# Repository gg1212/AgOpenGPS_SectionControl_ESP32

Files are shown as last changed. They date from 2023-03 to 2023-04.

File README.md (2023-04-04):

# AgOpenGPS Section Control ESP32 WiFi
This code runs AOG section control on ESP32. 
The ESP32 is connected to my mobile hotspot using WiFi, my laptop running AOG is also connected to the same WiFi hotspot. The AgIO UDP scanner will find the module once you configure the network address in AgIO. Note that you cannot fix the subnet of an Android hotspot so you may have to reconfigure subnet in AgIO if it switched on the phone.

You need to edit the code and add your WiFi SSID and password before uploading the code to ESP32.

That's a wiring diagram for 7sections, main(work) switch and manual/auto switch:

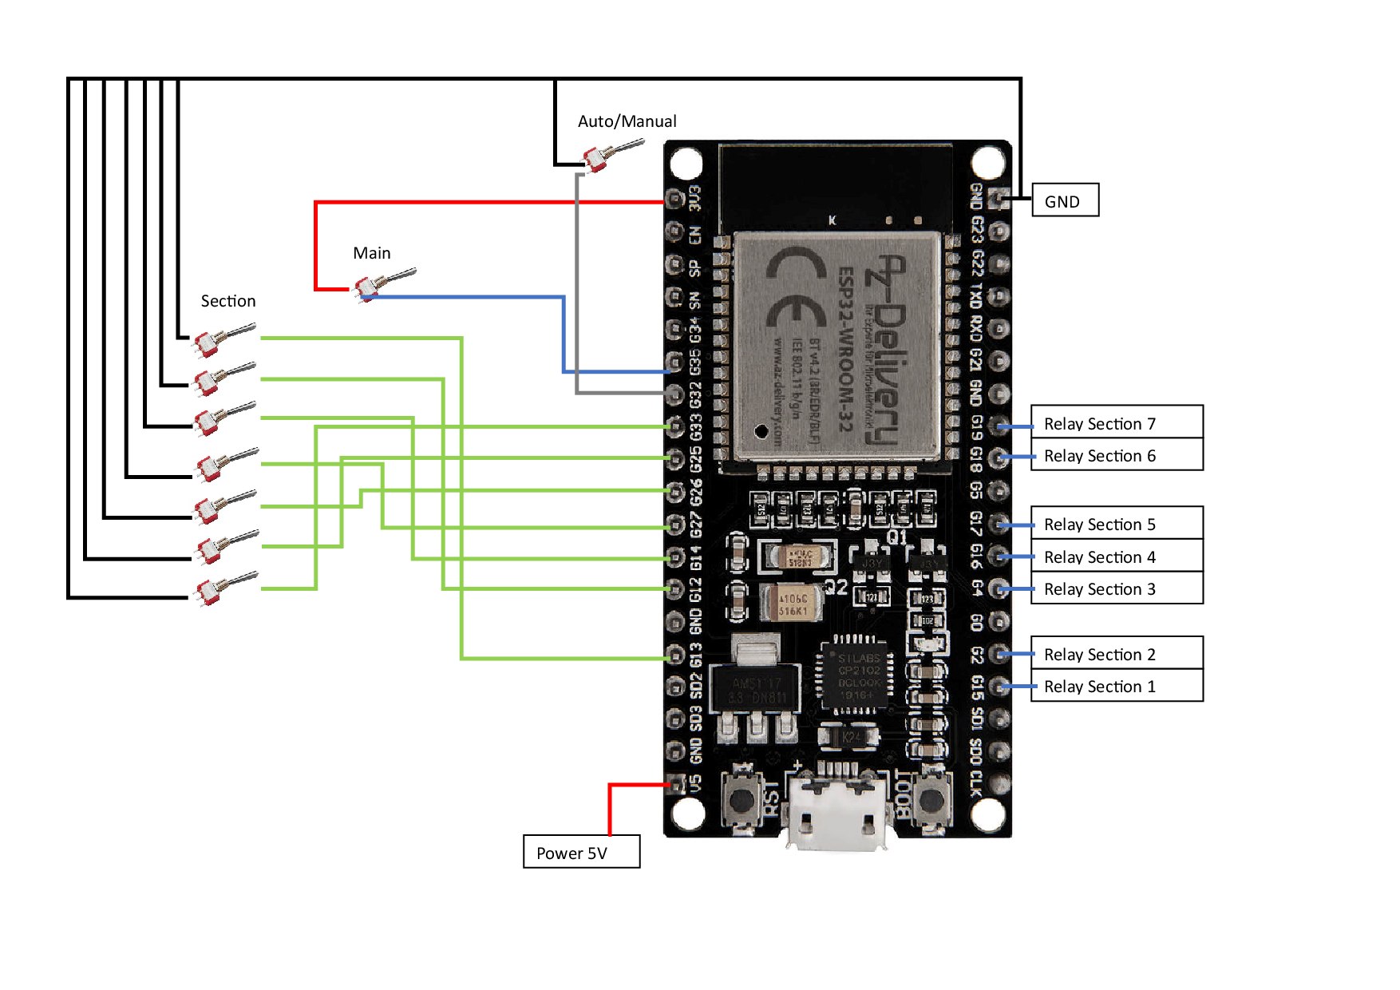
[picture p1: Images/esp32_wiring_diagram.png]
wiring diagram


This code is based on [mtz8302/AOG_SectionControl_ESP32](https://github.com/mtz8302/AOG_SectionControl_ESP32) for which all the rate control and web interface related stuff have been removed. The communication code has also been updated to make it ready for AOG v5.7.2 UDP.

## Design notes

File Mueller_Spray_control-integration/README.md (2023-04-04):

# Mueller Spray Control computer ESP32 Section Control
## Overview
The section control unit is connected between the existing Mueller Spray Control boxes and the sprayer. This allows me to do section control without any modification to the existing boxes and cables.

In manual mode, AOG displays the working area based on the section status.

In automatic mode, AOG controls the relays and the sprayer does GPS automatic section control based on AOG data.

The overview of my setup:

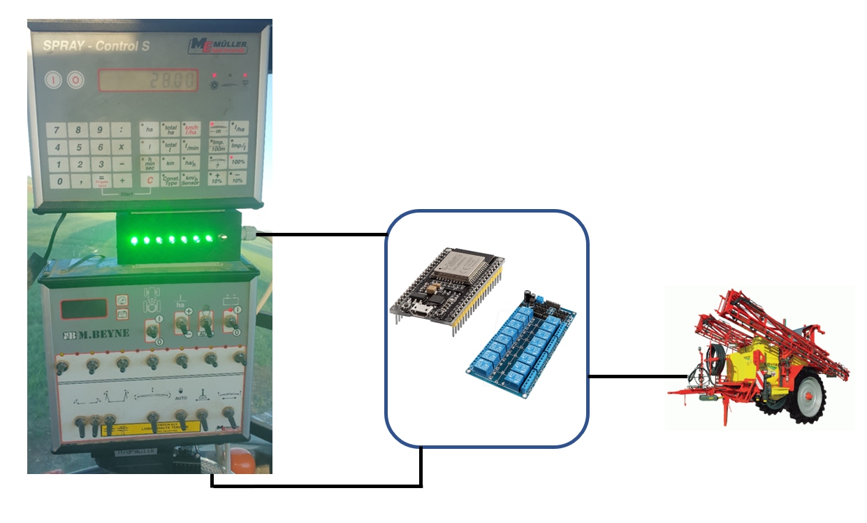
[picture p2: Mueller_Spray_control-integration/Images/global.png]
overview


## Reading section state from reverse polarity valves
My sprayer valves are reverse polarity, so to read the state on the ESP32, a PC817 8 channel board has been used. The section wire on which there is 12v when the section is open has been connected to the PC817 board.
There is also a bypass valve (reverse polarity too) on my sprayer and it has been connected to the 8th channel on the PC817 to activate the main(work) switch.

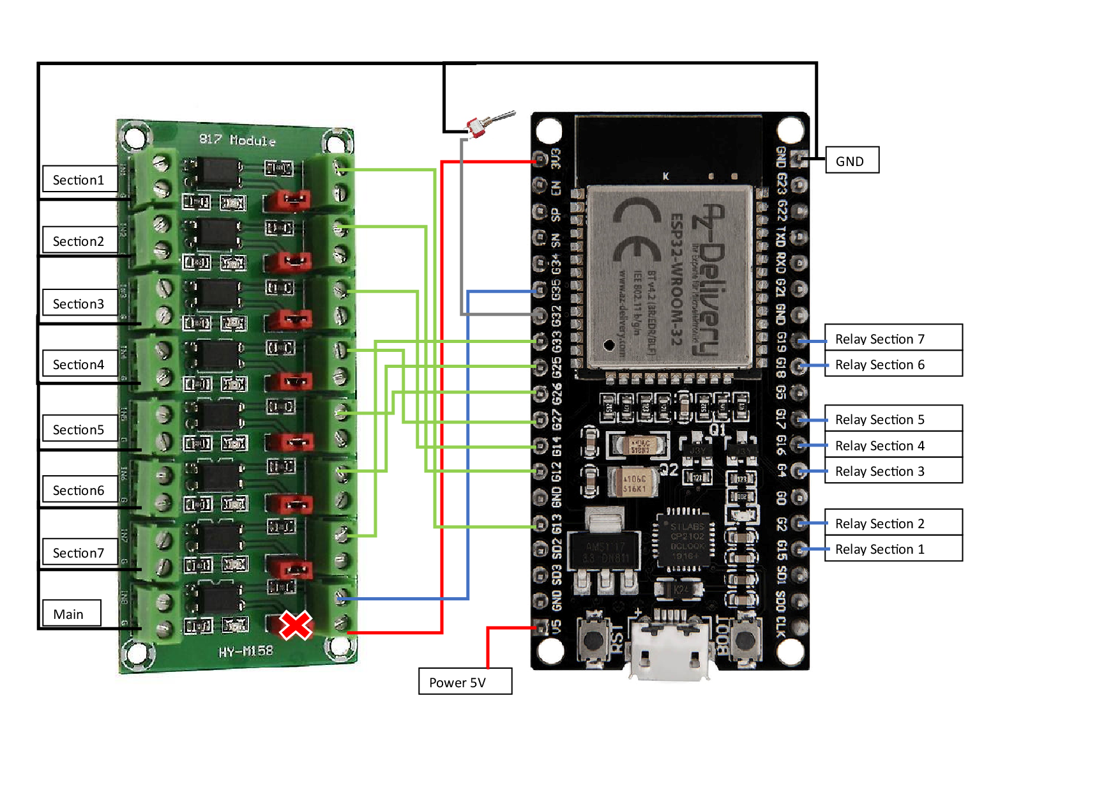
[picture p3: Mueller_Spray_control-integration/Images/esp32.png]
esp32


## Relay board & sending section status to rate computer
### Relay board
Valves are reverse polarity so you need 2 relays per section valve. 12V goes to NC of relay 1 and NO of relay 2. GND goes to NO of relay 1 and NC of relay 2. The section valve is connected to relay 1 & 2 COM.

So for my 7 sections sprayer, 14 relays of a 16 relays board have been used. They have been wired as in the example below.

### Rate controller section state
It is really important that the Spray Control computer knows how many sections are spraying in order to adjust rate correctly. So, the info should be coming from the output of the relays instead of the output of the switches as before. 

A second PC817 optocoupler board has been used to get the 12v status from relay board and switch rate computer pin to GND. Note that it requires to remove the 3K resistor so a wire has been soldered on the board to bypass it.

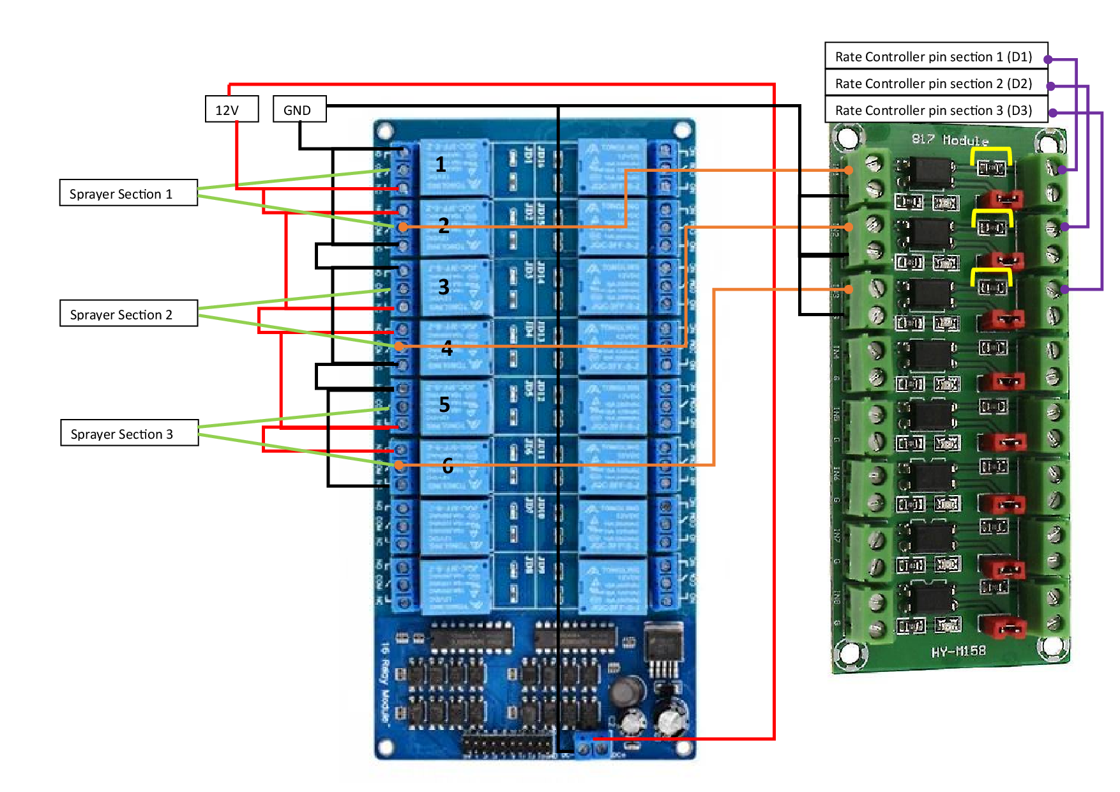
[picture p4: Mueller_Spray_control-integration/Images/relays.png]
relays


## Hardware
A 3D printed box that fits between Mueller Spray Control box and the switches box has been designed, it allows to connect to the Spray Control S box and send the section signal from real status(relay board+optocoupler). In order to centralize the switches, the man/auto switch has been put on this 3D printed box which fits perfectly like a 3rd Mueller box. 7 leds have also added to show the section state based on the relays as the original led only shows the switches state.

The box model is available in [3D](/Mueller_Spray_control-integration/3D) folder.

The connectors between Mueller boxes are Harting 48pins DIN 41612 connectors.

The connectors between Mueller box and sprayer are 30pins DIN 41622 connectors that I ordered at Beyne factory webshop : [30p male](https://erp.beyne.be/fr_BE/shop/product/cnc-30-m-prise-30-poles-m-4485) and [30p female](https://erp.beyne.be/fr_BE/shop/product/cnc-30-v-prise-30-poles-f-4483).

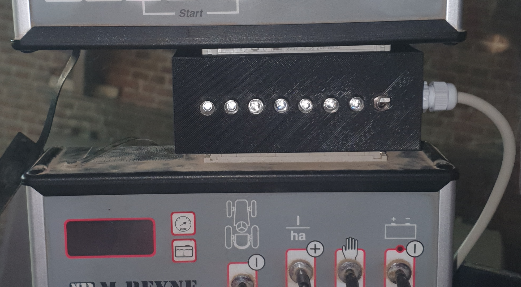
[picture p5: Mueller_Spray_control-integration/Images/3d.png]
3d box


## Mueller Pinout
### Spray Control S 48pins connector

|Pin|To |Info|
|---|---|----|
|Z3|Z3|12v|
|Z4|Z4|GND|
|Z6|Z6|GND|
|Z12|Z12|GND|
|B1|B1||
|B4|B4||
|B5|B5||
|B12|B12||
|B13|B13||
|D1|PC817-1|Section1|
|D2|PC817-2|Section2|
|D3|PC817-3|Section3|
|D4|PC817-4|Section4|
|D5|PC817-5|Section5|
|D6|PC817-6|Section6|
|D7|PC817-7|Section7|
|D13|D13||
|D14|D14||
|D15|D15||
|D16|D16||

### 30pin Sprayer connector
30pin DIN41622 - Input (from box)
|Pin|Info|To|
|--|--|--|
|A1|Rate|A1 Out|
|A2|Rate|A2 Out|
|A3|Main On/Off|PC817-8 + A3 Out|
|A4|Main On/Off|A4 Out|
|A5|Sec1|PC817-1|
|A6|Sec1||
|A7|Sec2|PC817-2|
|A8|Sec2||
|A9|Sec3|PC817-3|
|A10|Sec3||
|B1|Sec4|PC817-4|
|B2|Sec4||
|B3|Sec5|PC817-5|
|B4|Sec5||
|B5|Sec6|PC817-6|
|B6|Sec6||
|B7|Sec7|PC817-7|
|B8|Sec7||
|B9|Sec8|B9 Out|
|B10|Sec8|B10 Out|
|C1|Sec9|C1 Out|
|C2|Sec9|C2 Out|
|C3|12v|C3 + 12V|
|C4|unknow|C4 Out|
|C5|Gnd|C5 + GND|
|C6|unknow|C6 Out|
|C7|unknow|C7 Out|
|C8|unknow|C8 Out|
|C9|unknow|C9 Out|
|C10|unknow|C10 Out|

30pin DIN41622 - Output (To Sprayer)
|Pin|To|
|--|--|
|A1|A1 In|
|A2|A2 In|
|A3|A3 In|
|A4|A4 In|
|A5|Relay|
|A6|Relay|
|A7|Relay|
|A8|Relay|
|A9|Relay|
|A10|Relay|
|B1|Relay|
|B2|Relay|
|B3|Relay|
|B4|Relay|
|B5|Relay|
|B6|Relay|
|B7|Relay|
|B8|Relay|
|B9|B9 In|
|B10|B10 In|
|C1|C1 In|
|C2|C2 In|
|C3|C3 + 12V|
|C4|C4 In|
|C5|C5 + GND|
|C6|C6 In|
|C7|C7 In|
|C8|C8 In|
|C9|C9 In|
|C10|C10 In|

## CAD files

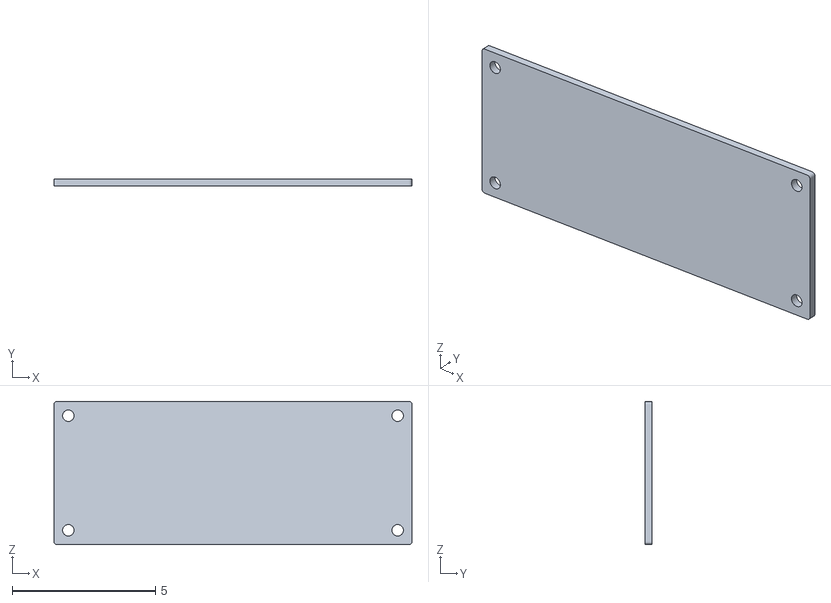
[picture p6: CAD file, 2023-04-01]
Mueller_Spray_control-integration/3D/top.stl
12.5 x 0.25 x 5.00

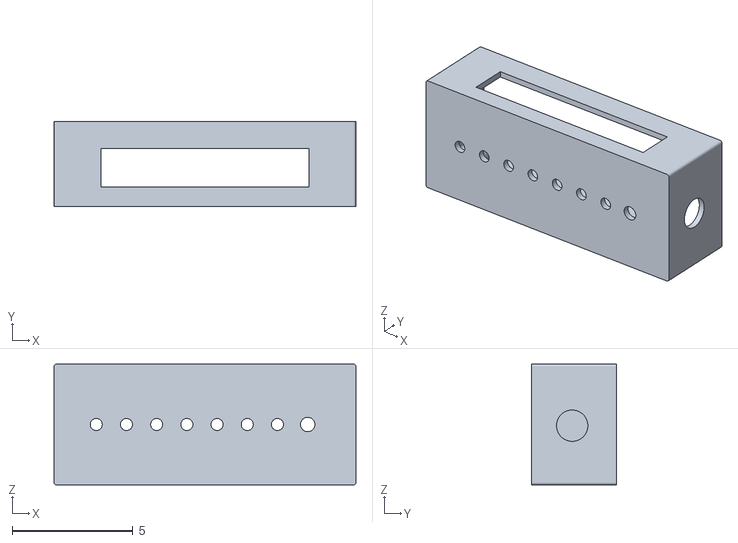
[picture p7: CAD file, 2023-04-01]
Mueller_Spray_control-integration/3D/box_mueller.stl
12.5 x 3.50 x 5.00

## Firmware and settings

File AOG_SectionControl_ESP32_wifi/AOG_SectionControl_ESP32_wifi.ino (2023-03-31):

// Section Control code for AgOpenGPS V5.7.2 for ESP32
// Wifi UDP only
// runs a wifi client and connect to mobile hotspot in the same network as AOG computer

// forked from MTZ8302 ESP32 SectionControl GitHub https://github.com/mtz8302
//
//
// Man/Auto pin switch to GND
// Section pin switch to GND
// Main pin switch to 3.3v
//
//

//libraries -------------------------------
#include "EEPROM.h"
#include "Update.h"
#include <WiFi.h>
#include <WiFiUdp.h>


byte vers_nr = 1;

struct set {
  //User config: ***********************************************************************************

  uint16_t BaudRate = 38400;              // Baudrate = speed of serial port or USB or Bluetooth. AOG uses 38400 for UART

  //the following lines should be configured by the user to fit the programm to the sprayer/ESP32
  //GPIOs of the ESP32 (current setting is for the layout shown as example WIKI)

  uint8_t SectNum = 7;					// number of sections
  uint8_t SectRelaysInst = 1;				// relays for SC output are equiped (0=no output, only documentation)
  uint8_t SectRelaysON = 0;				// relays spray on 1 or 0 (high or low)
  uint8_t Relay_PIN[16] = {15, 2, 4, 16, 17, 18, 19, 21, 255, 255, 255, 255, 255, 255, 255}; //GPIOs of ESP32 OUT to sections of sprayer HIGH/3.3V = ON
  uint8_t Relais_MainValve_PIN = 255;		// PIN for Main fluid valve 255 = unused
  uint8_t SectSWInst = 1;					// 1 if section input switches are equiped, else: 0
  uint8_t SectSWAutoOrOn = 0;				// Section switches spray/auto on 1 = high = used with pullup, 0 = low = pulldown
  uint8_t SectSW_PIN[16] = {13, 12, 14, 27, 26, 25, 33, 255, 255, 255, 255, 255, 255, 255}; //section switches to GPIOs of ESP32
  uint8_t	SectMainSWType = 1;				// 0 = not equiped 1 = (ON)-OFF-(ON) toggle switch or push buttons 2 = connected to hitch level sensor 3 = inverted hitch level sensor
  uint16_t	HitchLevelVal = 2000;		// Value for hitch level: switch AOG section control to Auto if lower than... ESP:2000 nano 500
  uint8_t	SectMainSW_PIN = 35;			// ESP32 to AOG Main auto toggle switch open=nothing/AOG button GND=OFF +3,3=AOG Auto on	OR connected to hitch level sensor
  uint8_t	SectAutoManSW_PIN = 32;			// Main Auto/Manual switch 39:!!no internal pullup!!

  uint8_t DocOnly = 0;					// 0: use as section control, 1: Documentation only = AOG writes the state of the input switches


  bool debugmode = false;
  bool debugmodeRelay = false;
  bool debugmodeSwitches = false;
  bool debugmodeDataFromAOG = false;
  bool debugmodeDataToAOG = false;

  // END of user config ****************************************************************************
}; set Set;

//Fill in your WiFi network info SSID and Password
const char* ssid = "";
const char* password = "";


bool EEPROM_clear = false;

unsigned long previousMillis = 0;
unsigned long interval = 5000;

WiFiUDP WiFiUDPFromAOG = WiFiUDP();
WiFiUDP WiFiUDPToAOG = WiFiUDP();

IPAddress WiFi_ipDestination, WiFi_Myip;
byte WiFi_ipDest_ending = 255;  

byte SCToAOG[14] = { 0x80, 0x81, 0x7B, 0xEA, 8, 0, 0, 0, 0, 0, 0, 0, 0, 0}, SCToAOGOld[14] = { 0x80, 0x81, 0x7B, 0xEA, 8, 0, 0, 0, 0, 0, 0, 0, 0, 0};

// sentences to AOG V5 -------------------------------------------------------------------
const byte FromAOGSentenceHeader[3] = { 0x80, 0x81, 0x7F };
#define SteerDataFromAOGHeader  0xFE  //take section info from steer packet
#define SCHelloFromAOG  0xC8

//write incoming Data to sentence array if it fits in
#define SentenceFromAOGMaxLength 14
byte SentenceFromAOG[SentenceFromAOGMaxLength], SentenceFromAOGLength;

//global, as serial/USB may not come at once, so values must stay for next loop
byte incomSentenceDigit = 0, DataToAOGLength = 14;

#define incommingDataArraySize 5
byte incommingBytes[incommingDataArraySize][500], incommingBytesArrayNr = 0, incommingBytesArrayNrToParse = 0;
unsigned int incommingDataLength[incommingDataArraySize] = { 0, 0, 0, 0, 0 };


TaskHandle_t taskHandle_DataFromAOGWiFi;

//values to decide position of section switch
#define SWOFF 650 // analog in is lower than .. for off
#define SWON 3000 // analog in is lower than .. for auto/on


//analog value of the toggle switches (default: middle=unpressed)
int MainSWVal = (SWOFF + SWON) / 2;
int MainSWValOld = (SWOFF + SWON) / 2;

//state of the switches HIGH = ON/Auto LOW = OFF
boolean SectSWVal[16] = { HIGH, HIGH, HIGH, HIGH, HIGH, HIGH, HIGH, HIGH, HIGH, HIGH, HIGH, HIGH, HIGH, HIGH, HIGH, HIGH };
boolean AutoSWVal = HIGH;
byte debugmodeSwitchesBak = 3;  //0 = false 1 = true 3 = not used

//loop time variables in microseconds
const unsigned long LOOP_TIME = 500;//in msec; 1000 = 1 Hz
const unsigned long SectSWDelayTime = 200;// 1500;//1400; //time the arduino waits after manual Switch is used before acception command from AOG in msec
unsigned long lastTime = LOOP_TIME;
unsigned long now = LOOP_TIME;
unsigned long DataFromAOGTime = 0;
unsigned long SectAutoSWTime = LOOP_TIME;
unsigned long SectAutoSWlastTime = LOOP_TIME;
unsigned long SectMainSWlastTime = LOOP_TIME;
unsigned long SectSWcurrentTime = LOOP_TIME;

//program flow

//bit 0 on byte[0] is section 1
byte SectGrFromAOG[] = { 0, 0 }; //Sections ON / OFF Bitwise !!!
byte RelayOUT[] = { 0, 0 }; //Sections ON / OFF Bitwise !!!
byte RelayOUTOld[] = { 0, 0 };
byte SectSWOffToAOG[] = { 0, 0 };
byte SectMainToAOG = 0;
byte uTurnRelay = 0;
boolean SectMainSWpressed = false;
boolean SectSWpressed = false;
boolean SectSWpressedLoop = false;
boolean SectAuto = true;
boolean SectAutoOld = true;
boolean SectAutoSWpressed = false;


boolean SectMainOn = false;

boolean newDataToAOG = false;

float gpsSpeed = 0; //speed from AgOpenGPS



void setup()
{
  delay(100);//wait for power to stabilize
  delay(100);//wait for IO chips to get ready
  //set up communication
  Serial.begin(Set.BaudRate);
  delay(10);
  delay(50);
  //get EEPROM data
  restoreEEprom();
  delay(100);
  
  //incomSentenceDigit = 0;
  
  //set GPIOs
  assignGPIOs();
  delay(50);

  //switches -> set relais
  if ((Set.SectSWInst) || (Set.SectMainSWType != 0)) {
    SectSWRead();
  }
  SetRelays();
  initWiFi();
  //get Data
  xTaskCreate(getDataFromAOGWiFi, "DataFromAOGHandleWiFi", 5000, NULL, 1, &taskHandle_DataFromAOGWiFi);

  delay(500);

}  //end setup


//-------------------------------------------------------------------------------------------------

void loop() {
  unsigned long currentMillis = millis();
  // if WiFi is down, try reconnecting
  if ((WiFi.status() != WL_CONNECTED) && (currentMillis - previousMillis >=interval)) {
    Serial.print(millis());
    Serial.println("Reconnecting to WiFi...");
    WiFi.disconnect();
    WiFi.reconnect();
    previousMillis = currentMillis;
  }
  
  //new data from AOG? Data comes via extra task and is written into byte array. Parsing called here
  if (incommingDataLength[incommingBytesArrayNrToParse] != 0) {
    parseDataFromAOG();
    vTaskDelay(5);
  }
  else {
    vTaskDelay(5);  //wait if no new data to give time to other tasks
  }
  //read switches/inputs
  if ((Set.SectSWInst) || (Set.SectMainSWType != 0))
  {
    SectSWRead(); //checks if section switch is toggled and sets RelayOUT

    //reset debugSwitches: has been change to true, if debugmodeDataToAOG = true for 1 loop
    if ((Set.debugmodeSwitches) && (debugmodeSwitchesBak == 0)) {
      Set.debugmodeSwitches = false;
    }

    SCToAOG[10] = SectSWOffToAOG[0]; //LowByte if bit set -> AOG section forced off
    SCToAOG[12] = SectSWOffToAOG[1]; //HiByte if bit set -> AOG section forced off
    SCToAOG[5] = SectMainToAOG; // Bits: AOG section control AUTO, Section control OFF, Rate L+R ...
    //new data?
    for (byte idx = 5; idx < DataToAOGLength; idx++) {
      if (SCToAOG[idx] != SCToAOGOld[idx]) {
        newDataToAOG = true;
        SCToAOGOld[idx] = SCToAOG[idx];
      }
    }
    
  }
  //no switches: set Relais as AOG commands
  else {
    RelayOUT[0] = SectGrFromAOG[0];
    RelayOUT[1] = SectGrFromAOG[1];
  }

  SetRelays();


  //timed loop: runs or if new data from switches to send data to AOG
  now = millis();
  if ((now > LOOP_TIME + lastTime) || (newDataToAOG)) {
    lastTime = now;
    //add the checksum
    int CRCtoAOG = 0;
    for (byte i = 2; i < sizeof(SCToAOG) - 1; i++)
    {
      CRCtoAOG = (CRCtoAOG + SCToAOG[i]);
    }
    SCToAOG[sizeof(SCToAOG) - 1] = CRCtoAOG;

    AOGDataSend(); 
    //send data to AOG in loop because using newdatatoAOG is not reliable if a UDP packet is lost
    if (newDataToAOG) {
      vTaskDelay(5);
      AOGDataSend(); //send data to AOG
      newDataToAOG = false;
    }
  }
}

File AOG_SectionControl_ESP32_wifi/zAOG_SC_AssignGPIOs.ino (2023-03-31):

void assignGPIOs() {
//#if HardwarePlatform == 0
	for (int i = 0; i < Set.SectNum; i++)
	{
		if (Set.SectSWInst) {
			if (Set.SectSW_PIN[i] < 255) { pinMode(Set.SectSW_PIN[i], INPUT_PULLUP); }
			else { Serial.print("no PIN set for section switch #"); Serial.println(i+1); }
			if (Set.Relay_PIN[i] < 255) { pinMode(Set.Relay_PIN[i], OUTPUT); }
			else { Serial.print("no PIN set for section relay #"); Serial.println(i+1); }
		}
	}
	if (Set.SectSWInst) {
		if (Set.SectAutoManSW_PIN < 255) { pinMode(Set.SectAutoManSW_PIN, INPUT_PULLUP); Serial.print("PIN ");Serial.print(Set.SectAutoManSW_PIN);Serial.print(" set for Auto/Manual switch"); }
		else { Serial.println("no PIN set for Auto/Manual toggle switch / buttons"); }
	}
	if (Set.SectMainSWType != 0) {
		if (Set.SectMainSW_PIN < 255) { pinMode(Set.SectMainSW_PIN, INPUT_PULLUP); Serial.print("PIN ");Serial.print(Set.SectMainSW_PIN);Serial.print(" set for Main switch"); }
		else { Serial.println("no PIN set for Main ON/OFF toggle switch / buttons"); }
	}

	if (Set.SectMainSW_PIN < 255) { pinMode(Set.Relais_MainValve_PIN, OUTPUT); }

	RelayOUT[0] = 0;
	RelayOUT[1] = 0;
	SetRelays();


//#endif


	//PWM rate settings Adjust to desired PWM Rate
	//TCCR1B = TCCR1B & B11111000 | B00000010;    // set timer 1 divisor to     8 for PWM frequency of  3921.16 Hz
	//TCCR1B = TCCR1B & B11111000 | B00000011;    // set timer 1 divisor to    64 for PWM frequency of   490.20 Hz (The DEFAULT)

}
